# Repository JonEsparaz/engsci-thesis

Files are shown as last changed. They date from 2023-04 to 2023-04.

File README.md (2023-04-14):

# Transforming Water Quality Sampling in Drinking Water Pipes via a Large Volume, Event-Based Sampling Device

Arduino source code, LabView VI, and CAD files for B.A.Sc. Thesis by Jonathan Esparaz (Engineering Science 2T2 + PEY, Machine Intelligence Major, University of Toronto).

## Project structure

The `ino` directory contains a single Arduino sketch that controls a prototype large volume, event-based sampling device. Associated wiring diagram:

arduino diagram

The solenoid valve requires an external 12V power supply, 220 ohm resistor, a TIP102 (NPN) transistor, and a IN4148 diode.

The `labview` directory contains a single LabView Virtual Instrument (VI) that records data from two [PX309-V150G5V pressure transducers](https://www.omega.ca/en/pressure-measurement/pressure-transducers/px309/p/PX309-V150G5V), one [G2S07N42GMX flow meter](https://www.omega.ca/en/flow-instruments/flow-meters/turbine-flow-meters/g2-series-gp/p/G2S07N42GMX), the output voltage from the Arduino used to control the solenoid valve (connection not represented in Arduino wiring diagram), and the output voltage from the Arduino turbidity sensor (connection not represented in Arduino wiring diagram). Data is saved to an Excel spreadsheet. Associated wiring diagram:

circuit

The flow meter requires an external 12V power supply and 250 ohm resistor.

The `cad` directory contains files that specify a custom adaptor for fitting the Arduino turbidity sensor in 1-inch PVC pipes (~60 PSI system pressure).

## Credits

Thank you to my thesis supervisors: Dr. David Meyer (Department of Civil & Mineral Engineering, University of Toronto) and Dr. Aaron Bivins (Department of Civil & Environmental Engineering, Louisiana State University). The LabView VI is based on example code provided by Dr. Meyer.

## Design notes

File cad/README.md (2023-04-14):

# CAD files

Files:
- `Modified_Tee_Joint_Approximation.stl`: approximate representation of a _modified_ [Thick-Wall PVC Inline Tee Reducer, 1 Socket Female x 1/2 Socket Female](https://www.mcmaster.com/4881K142/); top connection cut off using a hacksaw and widened using a file. 
- `Turbidity_Probe_Approximation.stl`: approximate representation of the turbidity sensor probe.
- `Custom_Turbidity_Mount.stl`: custom mount used to affix the turbidity sensor to the modified tee joint via u-bolts; fabricated using an Onyx One 3D printer from Markforged.
- `Turbidity_Sensor_Fit_Test.stl`: combination of modified tee joint, turbidity sensor probe, custom turbidity sensor mount, rubber o-ring, and steel u-bolts to test theoretical fit in CAD.
- `Turbidity_Sensor_Fit_Test_Cross_Section.stl`: cross-sectional view of previous file.

CAD files for the [rubber o-ring](https://www.mcmaster.com/1302N001/) and [steel u-bolts](https://www.mcmaster.com/8880T88/) can be downloaded from McMaster-Carr.

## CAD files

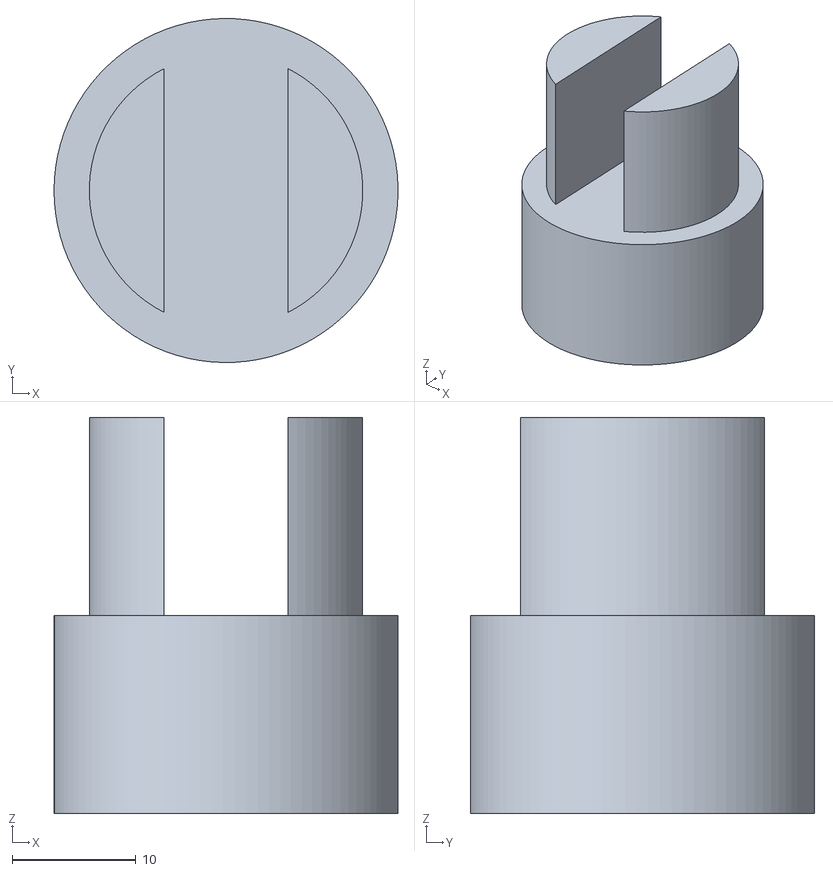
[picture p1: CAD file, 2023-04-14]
cad/Turbidity_Probe_Approximation.stl
27.8 x 27.8 x 32.0

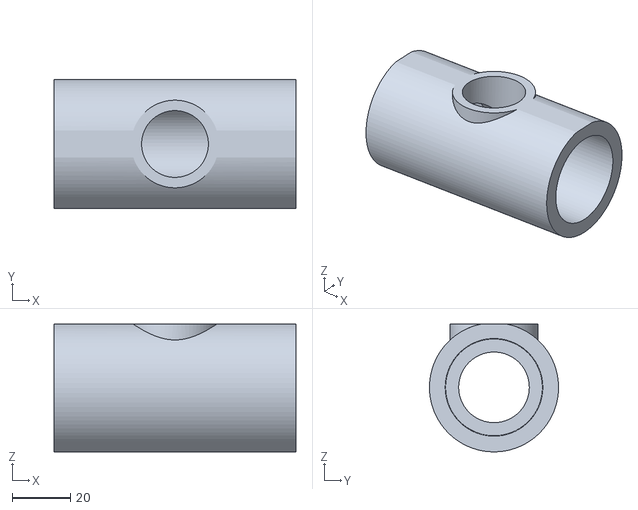
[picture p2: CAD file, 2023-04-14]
cad/Modified_Tee_Joint_Approximation.stl
83.3 x 44.4 x 44.0

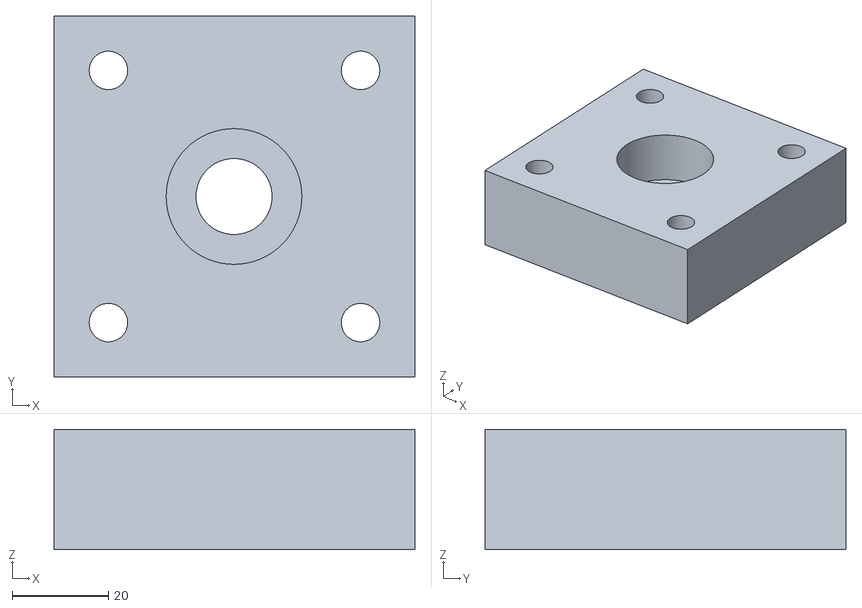
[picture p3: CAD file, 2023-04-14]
cad/Custom_Turbidity_Mount.stl
75.0 x 75.0 x 25.0

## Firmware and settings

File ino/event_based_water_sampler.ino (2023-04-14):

int FLOW_SENSOR_PIN = 2; // Interrupt-enabled pin
int SOLENOID_PIN = 12;

float ML_IN_L = 1000.0; // 1000 mL in 1 L
float SEC_IN_MIN = 60.0; // 60 seconds in 1 minute
float CAPTURE_VOLUME_ML = 1000.0; // 5 litres
float FLOW_SENSOR_CALIBRATION_FACTOR = 11.0; // From datasheet: F = 11 * Q (L/min)
float TURBIDITY_VOLTAGE_RANGE_CEIL   = 4.37;
float TURBIDITY_VOLTAGE_RANGE_FLOOR  = 3.7;
int TURBIDITY_COUNTER_THRESHOLD = 3;

int TURBIDITY_READ_PERIOD = 50; // 50 ms -> 20 Hz
float FLOW_RATE_READ_PERIOD = 250.0; // 0.25 seconds
float MAX_CAPTURE_LINE_OPEN_TIME = 300000.0; // 300,000 ms = 5 minutes

volatile byte pulseCount;  
unsigned long oldTime;
bool isSolenoidOpen;
float totalCaptureVolume;
float totalTimeValveOpen;
int turbidityThresholdCounter = 0;

void setup() {
  Serial.begin(9600);
  pinMode(SOLENOID_PIN, OUTPUT);
  pinMode(FLOW_SENSOR_PIN, INPUT);
  digitalWrite(FLOW_SENSOR_PIN, HIGH);
  attachInterrupt(digitalPinToInterrupt(FLOW_SENSOR_PIN), flowPulseCounter, FALLING);

  pulseCount = 0;
  oldTime = 0;
  totalCaptureVolume = 0.0;
  totalTimeValveOpen = 0.0;

  isSolenoidOpen = false;
  closeSolenoid();
}

void loop() {
  int sensorValue = analogRead(A5);
  float voltage = convertTurbiditySensorValueToVoltage(sensorValue);
  delay(TURBIDITY_READ_PERIOD);
  Serial.print("DATA(turbidity): ");
  Serial.println(voltage);

  if (isContaminantDetected(voltage)) {
    turbidityThresholdCounter++;
  } else {
    turbidityThresholdCounter = 0;    
  }

  if (turbidityThresholdCounter >= TURBIDITY_COUNTER_THRESHOLD && !isSolenoidOpen) {
    Serial.println("----------------------------------------------");
    Serial.println("INFO: turbidity sensor value passed threshold!");
    Serial.println("----------------------------------------------");
    openSolenoid();
    turbidityThresholdCounter = 0;
  }

  if (isSolenoidOpen) {
    if ((millis() - oldTime) > FLOW_RATE_READ_PERIOD) {
      detachInterrupt(digitalPinToInterrupt(FLOW_SENSOR_PIN));
      float flowRate = ((FLOW_RATE_READ_PERIOD / (millis() - oldTime)) * pulseCount) / FLOW_SENSOR_CALIBRATION_FACTOR;
      oldTime = millis();
      float flowMilliLitres = max(0, (flowRate / SEC_IN_MIN) * ML_IN_L);    
      totalCaptureVolume += flowMilliLitres;
      Serial.print("DATA(total_capture_volume): ");
      Serial.println(totalCaptureVolume);
      pulseCount = 0;
      attachInterrupt(digitalPinToInterrupt(FLOW_SENSOR_PIN), flowPulseCounter, FALLING);
      totalTimeValveOpen += FLOW_RATE_READ_PERIOD;
    }

    if (totalCaptureVolume >= CAPTURE_VOLUME_ML) {
      closeSolenoid();
      Serial.print("DATA(total_capture_time): ");
      Serial.println(totalTimeValveOpen);
    }

    if (totalTimeValveOpen >= MAX_CAPTURE_LINE_OPEN_TIME) {
      Serial.println("WARN: solenoid valve open timeout");
      closeSolenoid();
      Serial.print("DATA(total_capture_time): ");
      Serial.println(totalTimeValveOpen);
    }
  }
}

bool isContaminantDetected(float voltage) {
  // should detect suspended solids, but ignore air bubbles
  return (voltage < TURBIDITY_VOLTAGE_RANGE_CEIL) && (voltage > TURBIDITY_VOLTAGE_RANGE_FLOOR);
}

int openSolenoid() {
  if (!isSolenoidOpen) {
    Serial.println("INFO: opening solenoid valve");
    digitalWrite(SOLENOID_PIN, HIGH);
    pulseCount = 0;
    totalCaptureVolume = 0.0;
    totalTimeValveOpen = 0.0;
    isSolenoidOpen = true;
  } else {
    Serial.println("WARN: attempted to open solenoid valve while already open");
  }

  return 0;
}

int closeSolenoid() {
  if (isSolenoidOpen) {
    Serial.println("INFO: closing solenoid valve");
    digitalWrite(SOLENOID_PIN, LOW);
    isSolenoidOpen = false;
  } else {
    Serial.println("WARN: attempted to close solenoid valve while already closed");
  }

  return 0;
}

// scales 0-1023 analog reading to 0.00-5.00 volts 
float convertTurbiditySensorValueToVoltage(int sensorValue) {
  return sensorValue * (5.0 / 1024.0);
}

void flowPulseCounter() {
  pulseCount++;
}

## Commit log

2023-04-14 Add Arduino sketch
2023-04-14 Add CAD files
    [Custom_Turbidity_Mount.stl, Modified_Tee_Joint_Approximation.stl, Turbidity_Probe_Approximation.stl]
